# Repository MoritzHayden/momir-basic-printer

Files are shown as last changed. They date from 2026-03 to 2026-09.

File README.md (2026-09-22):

# Momir Basic Printer (MBP)

Momir Basic Printer (MBP) is a set of Python scripts designed to run headless on a Raspberry Pi connected to a thermal receipt printer for playing the [Momir Basic](https://magic.wizards.com/en/formats/momir-basic) MTG format.

If you are looking for the ESP32-based version, reference the [esp32](https://github.com/MoritzHayden/momir-basic-printer/tree/esp32) branch.

## Table of Contents

- [About](#about)
- [Momir Basic Rules](#momir-basic-rules)
- [Examples](#examples)
- [Hardware](#hardware)
  - [Components](#components)
  - [Diagram](#diagram)
  - [Photos](#photos)
- [Installation](#installation)
- [Service Management](#service-management)
- [Configuration](#configuration)
- [Disclaimer](#disclaimer)

## About

Downloads card data from the [Scryfall API](https://scryfall.com/docs/api), including card art which is dithered to monochrome on-device, and prints a random card within a set CMC value on demand via thermal printer. All settings are configurable via [config.ini](src/config.ini), and the software can run as a background service on any Linux-based SBC with GPIO. The complete hardware setup is designed to be compact and portable, with all components housed in a waterproof case.

## Momir Basic Rules

- Number of Players: 2
- Starting Life Total: 24
- Game Duration: 10 minutes
- Deck Size: 60+ basic lands

Each turn players discard a basic land to activate Momir Vig's ability and get a random creature from throughout Magic's history!

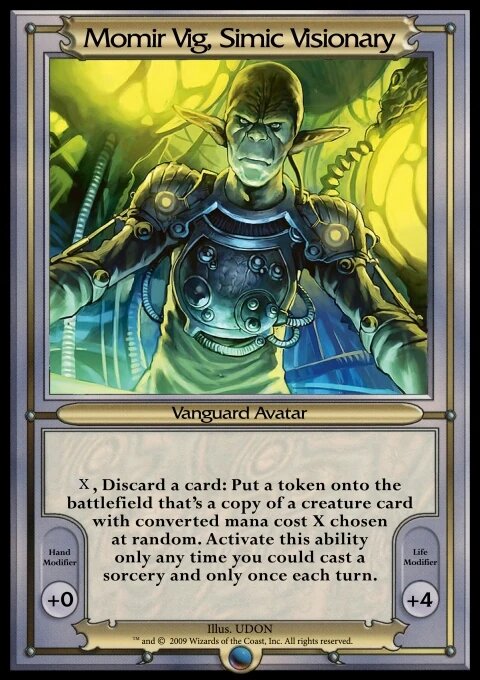
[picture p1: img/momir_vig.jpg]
Momir Vig, Simic Visionary


## Examples

| Physical Card | Printed Card |
| --- | --- |
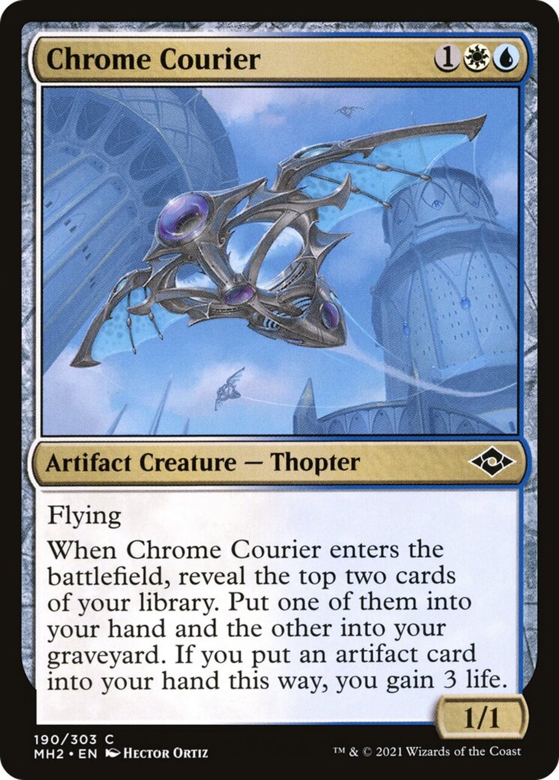
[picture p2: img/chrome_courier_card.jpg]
Physical Chrome Courier
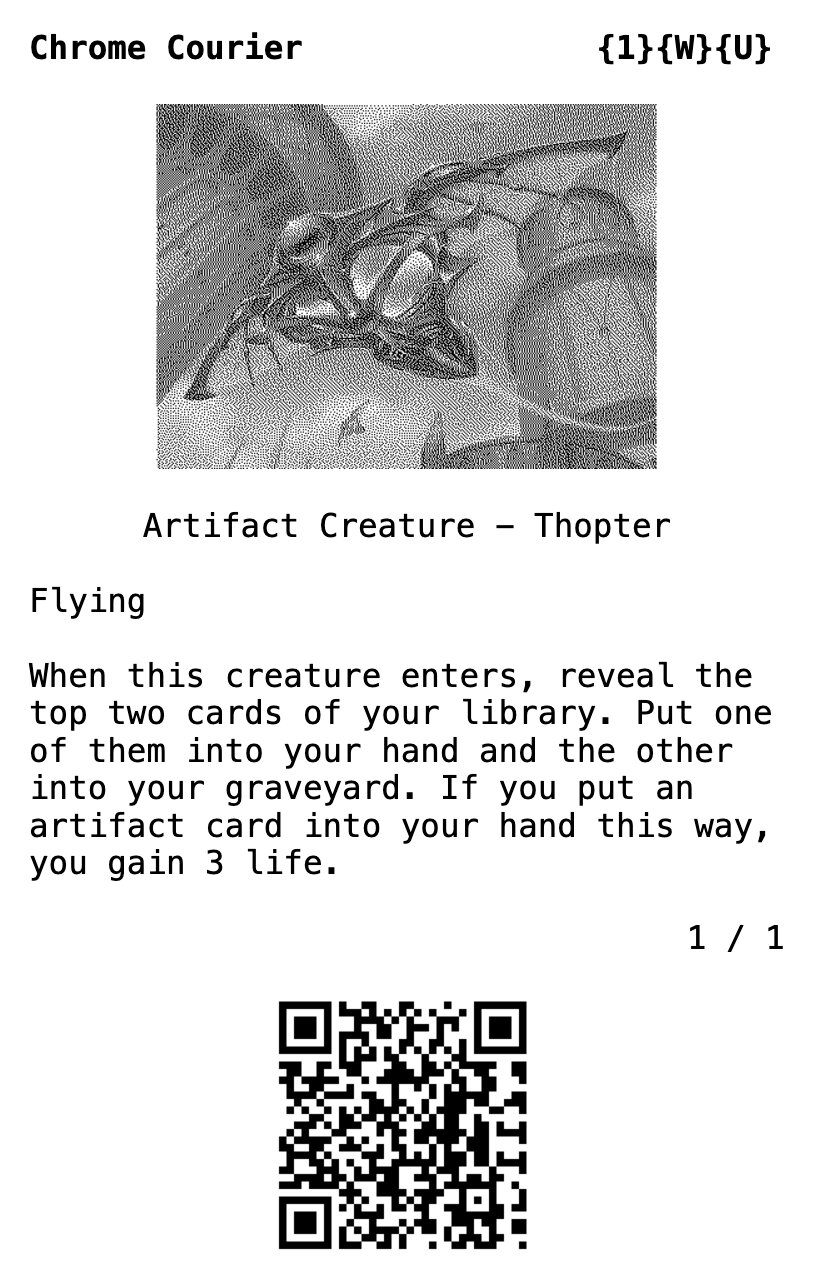
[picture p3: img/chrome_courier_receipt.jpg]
Printed Chrome Courier
|  |  |

## Hardware

### Components

- [Raspberry Pi 3 Model B+](https://www.raspberrypi.com/products/raspberry-pi-3-model-b-plus/)
- [Adafruit T-Cobbler Plus GPIO Breakout](https://a.co/d/0fnKGt3A)
- [REXQualis Electronics Component Kit](https://a.co/d/0cdCxCCP)
- [Maikrt MC206H Thermal Printer](https://a.co/d/06qIKsng)
- [PAPRMA 57mm x 30mm Thermal Paper](https://a.co/d/04u2Gb2j)
- [MakerFocus 20200330-SD8V OLED Display](https://a.co/d/06Y7V5Uj)
- [KY-040 Rotary Encoder Module](https://a.co/d/0hN4SBto)
- [Nilight 12V 20A SPST Rocker Toggle Switch](https://a.co/d/02VcvtcQ)
- [SHNITPWR 60W Universal Power Supply](https://a.co/d/0bKNzwey)
- [LM2596 Buck Converter](https://a.co/d/070NjEDp)
- [KeeYees 4 Channel IIC I2C Logic Level Converter](https://a.co/d/0ecOK7n6)
- [Enclosure Body](stl/enclosure_body.stl) ([source](https://www.printables.com/model/1735878-momir-basic-all-in-one-mtg-printer))
- [Enclosure Lid](stl/enclosure_lid.stl) ([source](https://www.printables.com/model/1735878-momir-basic-all-in-one-mtg-printer))

### Diagram

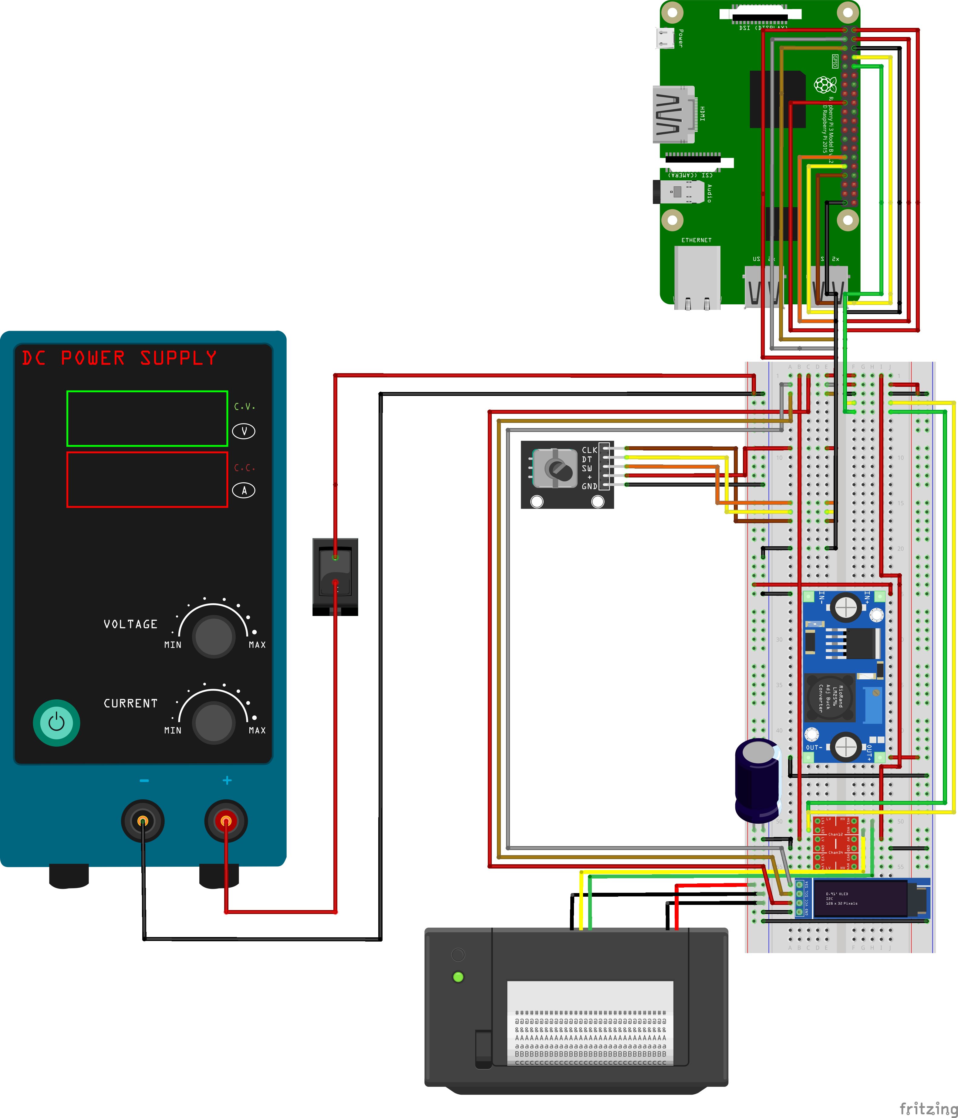
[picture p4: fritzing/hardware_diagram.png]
Hardware Diagram


### Photos

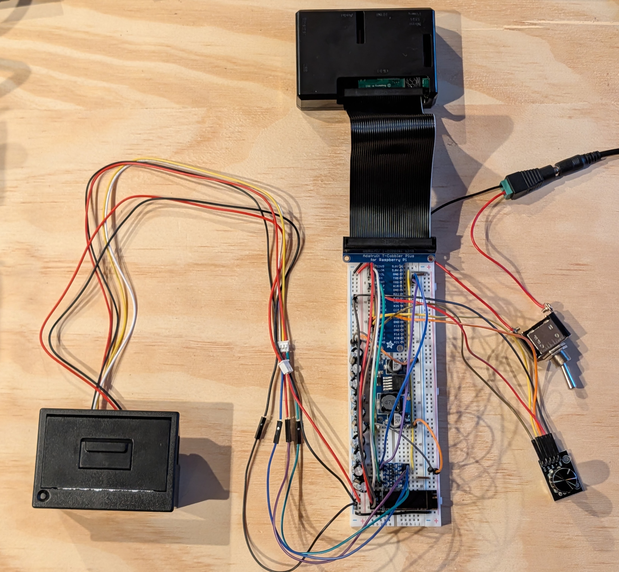
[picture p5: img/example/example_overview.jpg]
Example Overview


Example IO

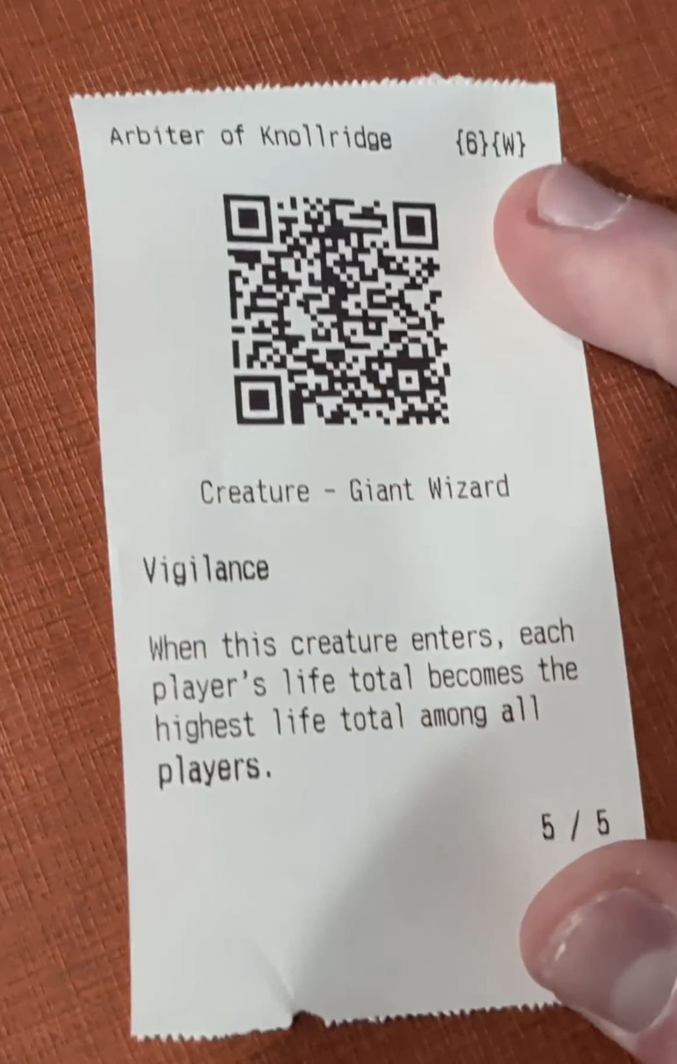
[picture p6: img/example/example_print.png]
Example Print


## Installation

1. Clone this repository and navigate to the project directory.

```shell
git clone https://github.com/MoritzHayden/momir-basic-printer.git
cd momir-basic-printer
```

2. Open [src/config.ini](src/config.ini) in a text editor and update the configuration variables to add your specific settings (like printer connection details, GPIO pins, and other hardware settings) before proceeding.

```shell
nano src/config.ini
```

3. Make the setup script executable and run it. This will automatically install dependencies and configure the systemd background service.

```shell
chmod +x setup.sh
./setup.sh
```

> [!TIP]
> If you are running a minimal setup and explicitly require the service to run as root, you can bypass the safety check by running: `sudo ./setup.sh --allow-root`

## Service Management

View live logs and print statements:

```shell
sudo journalctl -u momir-basic-printer.service -f
```

Check the current status of the service:

```shell
sudo systemctl status momir-basic-printer.service
```

Restart the service (required after making code changes):

```shell
sudo systemctl restart momir-basic-printer.service
```

Stop the service:

```shell
sudo systemctl stop momir-basic-printer.service
```

## Configuration

All configuration variables are stored in [src/config.ini](src/config.ini). Update the values in this file to match your specific hardware setup and preferences. After making changes to the configuration, restart the service for the changes to take effect.

| **Section**  | **Variable** | **Type**  | **Description** |
| --- | --- | --- | --- |
| `APP` | `booting_status` | `string`  | Status string shown while services initialize |
| `APP` | `ready_status` | `string`  | Status string shown when the appliance is idle/ready |
| `APP` | `refreshing_status` | `string`  | Status string shown during initial data refresh |
| `APP` | `fetching_status` | `string`  | Status string shown while selecting/fetching a card |
| `APP` | `printing_status` | `string`  | Status string shown while sending output to printer |
| `APP` | `cancelled_status` | `string`  | Status string shown when active work is cancelled |
| `APP` | `error_status` | `string`  | Status string shown when fetch/print fails |
| `APP` | `reset_status` | `string`  | Status string shown after long-press reset |
| `APP` | `done_status` | `string`  | Status string shown briefly after a successful print completes |
| `APP` | `done_status_seconds` | `float` | Duration in seconds to show `done_status` before returning to ready state |
| `APP` | `services_unavailable_status` | `string`  | Status string shown when printer/Scryfall services are unavailable |
| `APP` | `no_cmc_status_template` | `string`  | Template used when no card exists for selected CMC (supports `{cmc}`) |
| `APP` | `shutdown_join_timeout_seconds` | `float` | Max wait time for worker thread during shutdown |
| `FILESYSTEM` | `cards_path` | `string`  | Directory path where card JSON files are stored |
| `FILESYSTEM` | `art_path` | `string`  | Directory path where card artwork images are stored |
| `FILESYSTEM` | `default_card_art_path` | `string`  | File path to default placeholder image for cards without artwork |
| `FILESYSTEM` | `access_rights` | `octal` | File system permissions for created directories (octal notation) |
| `HARDWARE` | `serial_port` | `string`  | Serial device path for the thermal printer (e.g., `/dev/serial0`) |
| `HARDWARE` | `serial_baud_rate` | `integer` | Baud rate for the serial printer connection (e.g., `9600` or `19200`) |
| `HARDWARE` | `printer_dtr_enabled` | `boolean` | Enables GPIO-based DTR flow control; disable if the printer does not wire DTR reliably |
| `HARDWARE` | `gpio_encoder_clk` | `integer` | BCM GPIO pin for rotary encoder CLK signal (default: `13`) |
| `HARDWARE` | `gpio_encoder_dt` | `integer` | BCM GPIO pin for rotary encoder DT signal (default: `6`) |
| `HARDWARE` | `gpio_encoder_sw` | `integer` | BCM GPIO pin for rotary encoder push-button switch (default: `5`) |
| `HARDWARE` | `gpio_printer_dtr` | `integer` | BCM GPIO pin for printer DTR hardware flow control (default: `17`) |
| `HARDWARE` | `printer_dtr_active_high` | `boolean` | Whether the printer asserts DTR HIGH when its receive buffer is full |
| `HARDWARE` | `i2c_address` | `hex` | I2C hex address of the SSD1306 OLED display (default: `0x3C`) |
| `HARDWARE` | `i2c_port` | `integer` | I2C bus port number (default: `1`) |
| `HARDWARE` | `oled_width` | `integer` | OLED display width in pixels (default: `128`) |
| `HARDWARE` | `oled_height` | `integer` | OLED display height in pixels (default: `64`) |
| `HARDWARE` | `display_font_size_cmc` | `integer` | Font size for the main CMC text on OLED |
| `HARDWARE` | `display_font_size_status` | `integer` | Font size for the status text on OLED |
| `HARDWARE` | `display_status_y_offset` | `integer` | Vertical Y offset (px) for status text region |
| `HARDWARE` | `display_status_default` | `string`  | Default status text shown during display initialization |
| `HARDWARE` | `display_font_cmc_path` | `string`  | Font file path used for CMC text rendering |
| `HARDWARE` | `display_font_status_path` | `string`  | Font file path used for status text rendering |
| `HARDWARE` | `display_cmc_prefix` | `string`  | Prefix label used before current CMC value (e.g., `CMC:`) |
| `HARDWARE` | `display_padding_x` | `integer` | Left/right OLED padding in pixels for CMC and status text layout |
| `HARDWARE` | `display_cmc_value_gap` | `integer` | Horizontal pixel gap between the CMC prefix label and numeric CMC value |
| `HARDWARE` | `hold_time` | `float` | Seconds the encoder button must be held for a long-press action |
| `HARDWARE` | `cmc_min` | `integer` | Minimum selectable CMC value (default: `0`) |
| `HARDWARE` | `cmc_max` | `integer` | Maximum selectable CMC value (default: `16`) |
| `HARDWARE` | `dtr_poll_interval` | `float` | Seconds between DTR pin polls when printer buffer is full |
| `HARDWARE` | `printer_dtr_timeout_seconds` | `float` | Max time to wait on DTR before bypassing hardware flow control until restart |
| `LOGGING` | `log_level` | `string`  | Logging verbosity level (`DEBUG`, `INFO`, `WARNING`, `ERROR`, `CRITICAL`) |
| `LOGGING` | `log_format` | `string`  | Format string for log messages |
| `LOGGING` | `log_date_format` | `string`  | Format string for timestamps in log messages |
| `PRINTER` | `paper_width_mm` | `integer` | Physical width of thermal paper in millimeters |
| `PRINTER` | `paper_width_chars` | `integer` | Maximum number of characters per line for text wrapping |
| `PRINTER` | `card_art_enabled` | `boolean` | Whether to print card artwork images on receipts |
| `PRINTER` | `qr_code_enabled` | `boolean` | Whether to print QR codes linking to Scryfall card details |
| `PRINTER` | `qr_code_size` | `integer` | Size of QR code in printer units (larger = bigger QR code) |
| `PRINTER` | `dpi` | `integer` | Printer resolution in dots per inch for image rendering |
| `PRINTER` | `vendor_id` | `hex` | USB vendor ID for the thermal printer device |
| `PRINTER` | `product_id` | `hex` | USB product ID for the thermal printer device |
| `PRINTER` | `printer_profile` | `string`  | ESC/POS printer profile name for compatibility |
| `PRINTER` | `printer_media_width_px` | `integer` | Media width in pixels for image processing and scaling |
| `PRINTER` | `min_title_spacing` | `integer` | Minimum spaces between card name and mana cost on title line |
| `PRINTER` | `paragraph_spacing` | `string`  | Escaped spacing appended after wrapped oracle text paragraphs |
| `PRINTER` | `text_replacements_json` | `json` | Character replacement map for printer-safe text normalization |
| `SCRYFALL` | `base_url` | `string`  | Base URL for Scryfall API requests |
| `SCRYFALL` | `bulk_data_endpoint` | `string`  | API endpoint path for bulk card data download |
| `SCRYFALL` | `header_accept` | `string`  | HTTP Accept header value for API content negotiation |
| `SCRYFALL` | `header_user_agent` | `string`  | HTTP User-Agent header identifying the client application |
| `SCRYFALL` | `header_accept_encoding` | `string`  | HTTP Accept-Encoding header for compression support |
| `SCRYFALL` | `request_delay_seconds` | `float` | Delay between consecutive API requests to respect rate limits |
| `SCRYFALL` | `max_retries` | `integer` | Maximum number of retry attempts for failed API requests |
| `SCRYFALL` | `art_width_px` | `integer` | Target width in pixels for downloaded card artwork |
| `SCRYFALL` | `excluded_sets` | `list` | Comma-separated card sets to exclude (e.g., `funny`, `memorabilia`) |
| `SCRYFALL` | `excluded_layouts` | `list` | Comma-separated card layouts to exclude (e.g., `token`, `emblem`) |

## Disclaimer

Neither this project nor its contributors are associated with Hasbro, Wizards of the Coast, or _Magic: The Gathering_ in any way whatsoever.

<div align="center">
  <p>Copyright &copy; 2026 Hayden Moritz</p>
</div>

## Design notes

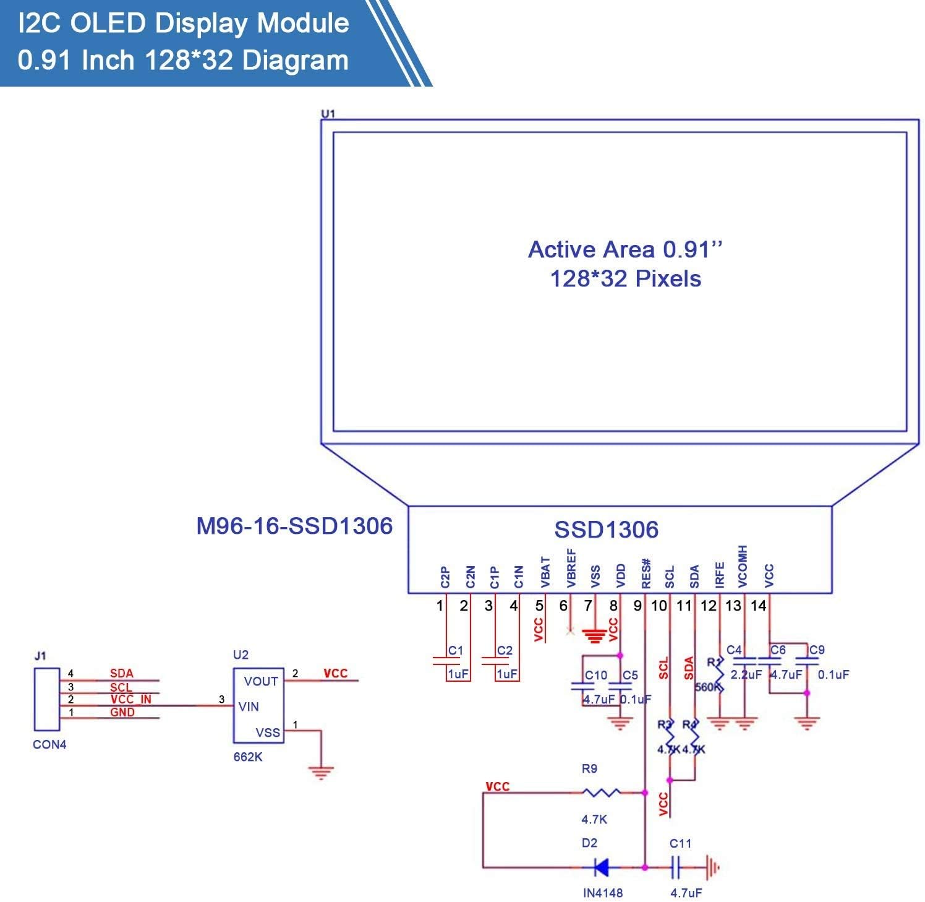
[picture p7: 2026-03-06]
img/reference/oled_display_pinout.jpg

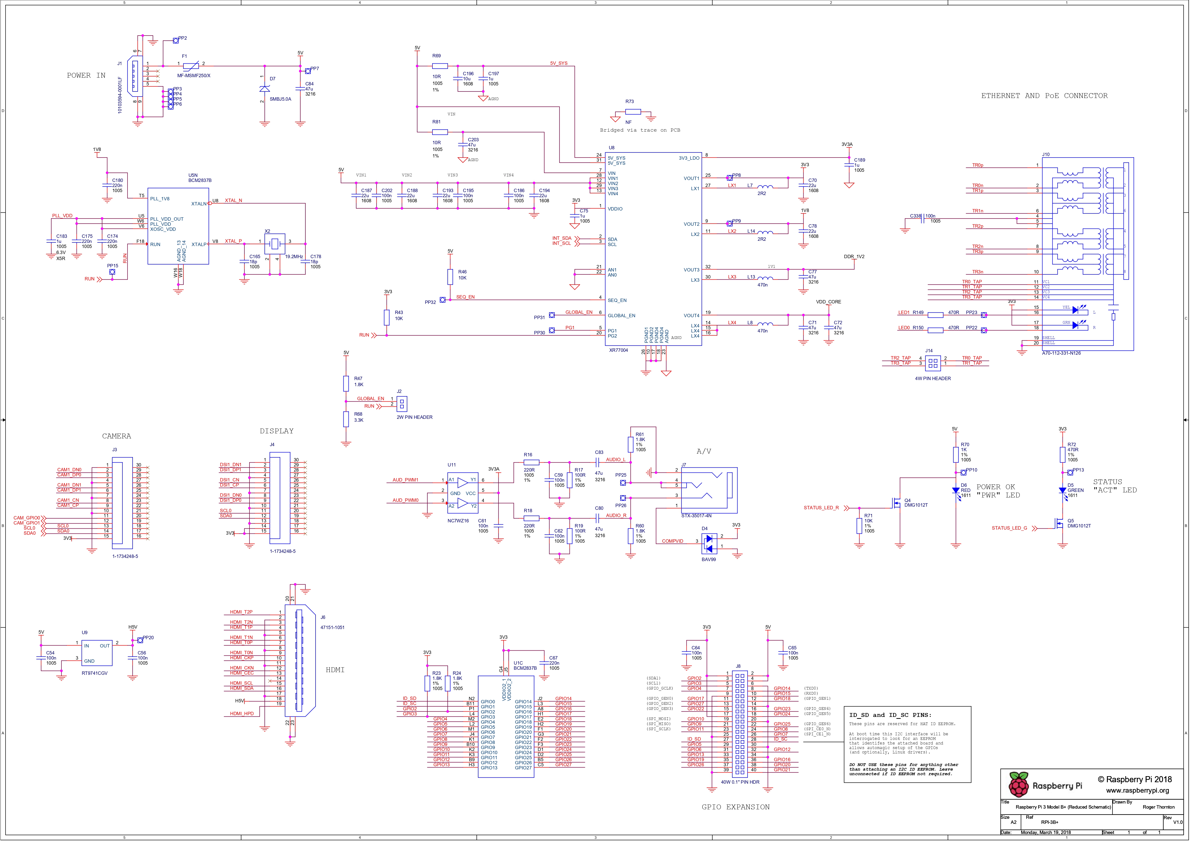
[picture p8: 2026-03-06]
img/reference/raspberry_pi_schematic.jpg

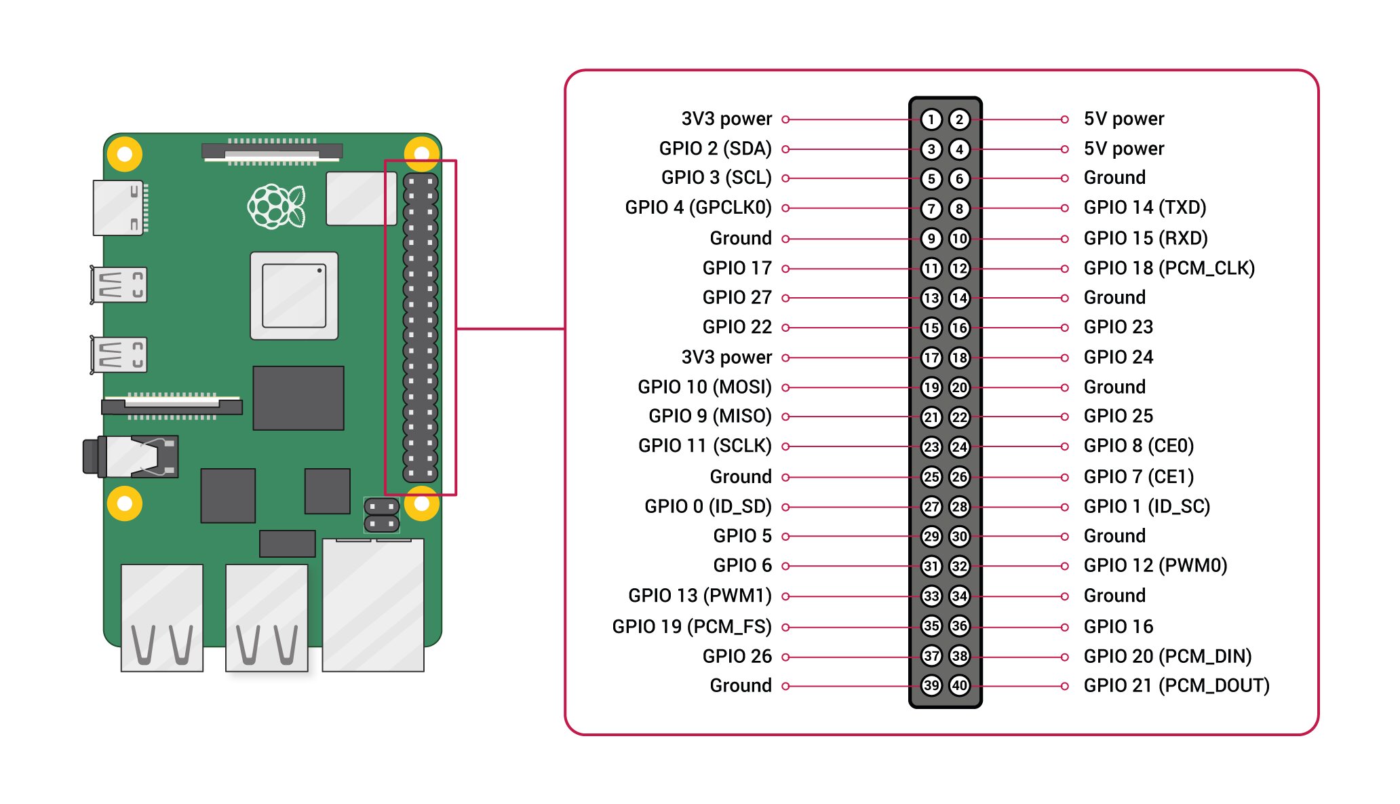
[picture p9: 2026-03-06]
img/reference/raspberry_pi_gpio_pinout_1.jpg

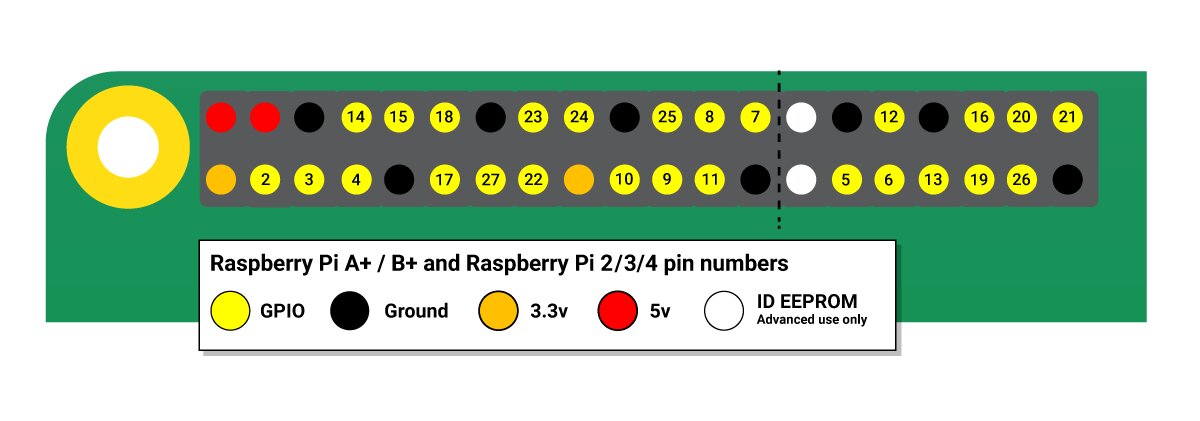
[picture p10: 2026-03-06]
img/reference/raspberry_pi_gpio_pinout_2.jpg

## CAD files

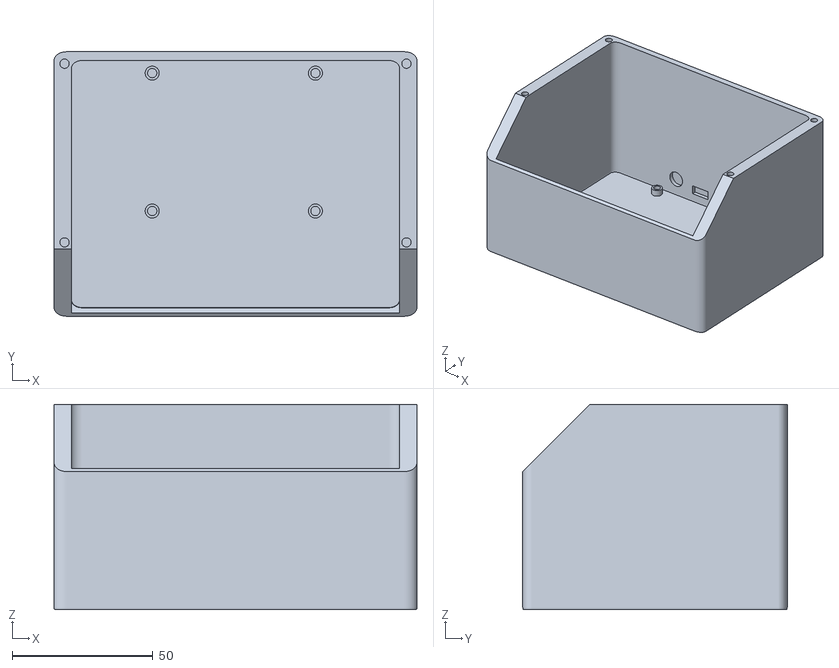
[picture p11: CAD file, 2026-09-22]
stl/enclosure_body.stl
129.0 x 94.0 x 73.0

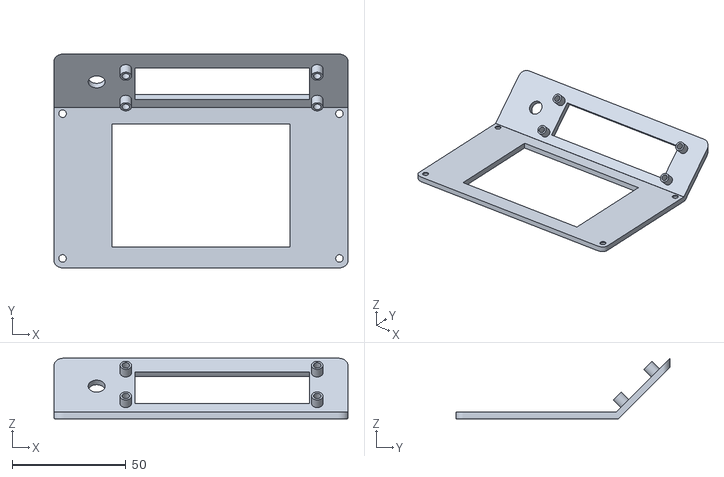
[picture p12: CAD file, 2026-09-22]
stl/enclosure_lid.stl
129.0 x 94.0 x 26.7

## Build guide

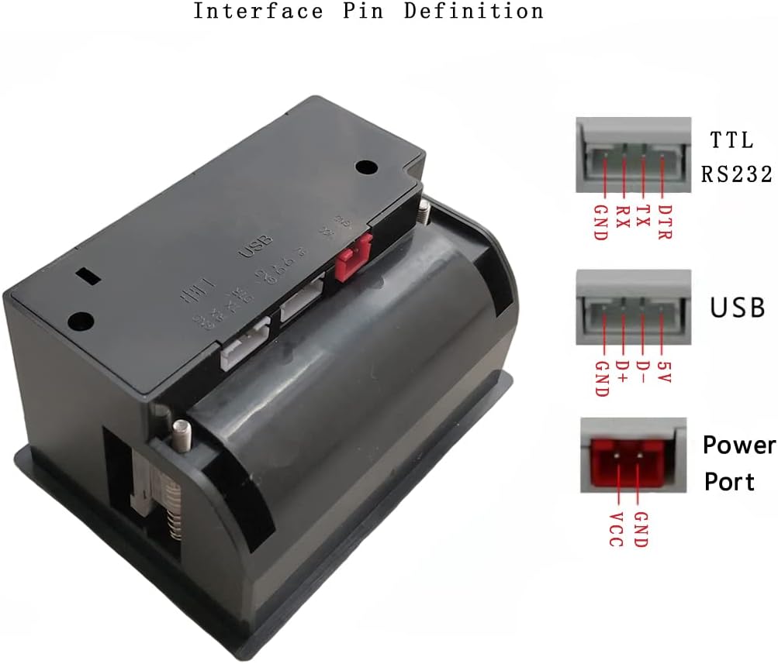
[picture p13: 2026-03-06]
img/reference/thermal_printer_pinout.jpg

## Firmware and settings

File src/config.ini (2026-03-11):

[APP]
booting_status = Booting...
ready_status = Ready
refreshing_status = Refreshing...
fetching_status = Fetching...
printing_status = Printing...
cancelled_status = Cancelled
error_status = Error
reset_status = Reset
services_unavailable_status = Services N/A
no_cmc_status_template = No CMC {cmc}
shutdown_join_timeout_seconds = 5
printed_status_name_max_len = 20

[FILESYSTEM]
cards_path = ./cards
art_path = ./cards/art
default_card_art_path = ./img/default_card_art.jpg
access_rights = 0o777

[HARDWARE]
serial_port = /dev/serial0
serial_baud_rate = 9600
printer_dtr_enabled = True
gpio_encoder_clk = 13
gpio_encoder_dt = 6
gpio_encoder_sw = 5
gpio_printer_dtr = 17
printer_dtr_active_high = True
i2c_address = 0x3C
i2c_port = 1
oled_width = 128
oled_height = 64
display_font_size_cmc = 36
display_font_size_status = 12
display_status_y_offset = 52
display_status_default = Ready
display_font_cmc_path = /usr/share/fonts/truetype/dejavu/DejaVuSans-Bold.ttf
display_font_status_path = /usr/share/fonts/truetype/dejavu/DejaVuSans.ttf
display_cmc_prefix = CMC:
hold_time = 1.5
cmc_min = 0
cmc_max = 16
dtr_poll_interval = 0.05
printer_dtr_timeout_seconds = 3.0

[LOGGING]
log_level = DEBUG
log_format = [%%(levelname)s] [%%(asctime)s] %%(name)s: %%(message)s
log_date_format = %%Y-%%m-%%d %%H:%%M:%%S

[PRINTER]
paper_width_mm = 57
paper_width_chars = 38
card_art_enabled = True
qr_code_enabled = True
qr_code_size = 6
dpi = 203
vendor_id = 0x1234
product_id = 0x5678
printer_profile = simple
printer_media_width_px = 380
min_title_spacing = 1
paragraph_spacing = \n\n
text_replacements_json = {"\u2014":"-","\u2013":"-","\u2019":"'","\u201c":"\"","\u201d":"\""}

[SCRYFALL]
base_url = https://api.scryfall.com
bulk_data_endpoint = /bulk-data/oracle_cards
header_accept = application/json
header_user_agent = MoritzHayden/momir-basic-printer
header_accept_encoding = gzip
request_delay_seconds = 0.05
max_retries = 3
art_width_px = 380
excluded_sets = funny,
                memorabilia,
                minigame,
                alchemy
excluded_layouts = token,
                   emblem,
                   art_series,
                   double_faced_token,
                   scheme,
                   planar,
                   phenomenon,
                   vanguard,
                   augment,
                   host

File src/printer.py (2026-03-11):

"""Thermal printer interface for printing Magic: The Gathering cards."""

import logging
import json
import threading
import textwrap
import time
from pathlib import Path
from typing import Any, Dict, Optional

import gpiozero
from escpos.printer import Serial
from PIL import Image

logger = logging.getLogger('momir.printer')


class Printer:
    """Thermal printer interface for printing Magic: The Gathering cards.

    This class handles:
    - Formatting card data for thermal printer output
    - Printing card images, text, and QR codes
    - Text cleaning and wrapping for proper display
    - DTR-based hardware flow control on the serial thermal printer
    """

    def __init__(self, printer_config, filesystem_config, hardware_config=None) -> None:
        """Initialize printer with configuration.

        Args:
            printer_config: Configuration section for printer settings
            filesystem_config: Configuration section for filesystem paths
            hardware_config: Optional configuration section for GPIO/serial settings
        """
        # Printer configuration
        self.paper_width_mm: int = printer_config.getint('paper_width_mm')
        self.paper_width_chars: int = printer_config.getint(
            'paper_width_chars')
        self.card_art_enabled: bool = printer_config.getboolean(
            'card_art_enabled')
        self.qr_code_enabled: bool = printer_config.getboolean(
            'qr_code_enabled')
        self.qr_code_size: int = printer_config.getint('qr_code_size')
        self.dpi: int = printer_config.getint('dpi')
        self.vendor_id: int = int(printer_config.get('vendor_id'), 0)
        self.product_id: int = int(printer_config.get('product_id'), 0)

        # Serial configuration (from [HARDWARE] or fallbacks)
        if hardware_config is not None:
            self.serial_port: str = hardware_config.get(
                'serial_port', fallback='/dev/serial0')
            self.serial_baud_rate: int = hardware_config.getint(
                'serial_baud_rate', fallback=9600)
            self._dtr_enabled: bool = hardware_config.getboolean(
                'printer_dtr_enabled', fallback=True)
            self._dtr_pin: int = hardware_config.getint(
                'gpio_printer_dtr', fallback=17)
            self._dtr_active_high: bool = hardware_config.getboolean(
                'printer_dtr_active_high', fallback=True)
            self._dtr_poll_interval: float = hardware_config.getfloat(
                'dtr_poll_interval', fallback=0.05)
            self._dtr_timeout_seconds: float = hardware_config.getfloat(
                'printer_dtr_timeout_seconds', fallback=3.0)
        else:
            self.serial_port = '/dev/serial0'
            self.serial_baud_rate = 9600
            self._dtr_enabled = True
            self._dtr_pin = 17
            self._dtr_active_high = True
            self._dtr_poll_interval = 0.05
            self._dtr_timeout_seconds = 3.0

        self._dtr_disabled_runtime = not self._dtr_enabled

        self.printer_profile: str = printer_config.get(
            'printer_profile', fallback='simple')
        self.printer_media_width_px: Optional[int] = printer_config.getint(
            'printer_media_width_px', fallback=None)
        self._min_title_spacing: int = printer_config.getint('min_title_spacing', fallback=1)
        self._paragraph_spacing: str = printer_config.get(
            'paragraph_spacing', fallback='\\n\\n').encode('utf-8').decode('unicode_escape')
        text_replacements_json = printer_config.get(
            'text_replacements_json',
            fallback='{"\\u2014":"-","\\u2013":"-","\\u2019":"\'","\\u201c":"\\\"","\\u201d":"\\\""}',
        )
        try:
            self._text_replacements: Dict[str, str] = json.loads(text_replacements_json)
        except json.JSONDecodeError as exc:
            raise ValueError(f"Invalid text_replacements_json in config: {exc}") from exc

        # DTR monitoring is optional because some printers leave the line floating.
        self._dtr_device = None
        if self._dtr_enabled:
            self._dtr_device = gpiozero.InputDevice(self._dtr_pin, pull_up=False)

        # Filesystem paths (use __file__ for reliability)
        base_path = Path(__file__).resolve().parent.parent
        self.cards_path: Path = base_path / filesystem_config.get('cards_path')
        self.art_path: Path = base_path / filesystem_config.get('art_path')
        self.default_card_art_path: Path = base_path / \
            filesystem_config.get('default_card_art_path')
        self.access_rights: int = int(
            filesystem_config.get('access_rights'), 0)

        # Ensure runtime directories exist so app can boot on a fresh install.
        self.cards_path.mkdir(parents=True, exist_ok=True, mode=self.access_rights)
        self.art_path.mkdir(parents=True, exist_ok=True, mode=self.access_rights)

        # Validate configuration
        self._validate_config()

    def _validate_config(self) -> None:
        """Validate critical configuration values on initialization.

        Raises:
            ValueError: If critical configuration is missing or invalid
        """
        if self.paper_width_chars <= 0:
            raise ValueError(
                f"paper_width_chars must be positive, got {self.paper_width_chars}")

        if self.qr_code_size <= 0:
            raise ValueError(
                f"qr_code_size must be positive, got {self.qr_code_size}")

        if self.printer_media_width_px is not None and self.printer_media_width_px <= 0:
            raise ValueError(
                "printer_media_width_px must be positive when provided")

    def __repr__(self) -> str:
        """String representation for debugging."""
        return (f"Printer(serial='{self.serial_port}', "
                f"baud={self.serial_baud_rate}, "
            f"profile='{self.printer_profile}', "
            f"paper_width_chars={self.paper_width_chars})")

    def clean_text(self, text: str) -> str:
        """Clean text for thermal printer compatibility.

        Replaces special Unicode characters with ASCII equivalents
        that the thermal printer can handle.

        Args:
            text: Input text to clean

        Returns:
            Cleaned text with replaced characters
        """
        cleaned = text
        for old_char, new_char in self._text_replacements.items():
            cleaned = cleaned.replace(old_char, new_char)
        # Encode to CP437 (standard ASCII/IBM code page) so that python-escpos's
        # MagicEncode never needs to switch to a non-Latin codepage (e.g. GBK).
        # Characters outside CP437 are replaced with '?' rather than triggering
        # a codepage switch that would corrupt the entire subsequent print stream.
        cleaned = cleaned.encode('cp437', errors='replace').decode('cp437')
        return cleaned

    def _is_dtr_busy(self) -> bool:
        if self._dtr_device is None:
            return False
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

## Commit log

2026-03-05 feat: add printer virtualization
2026-03-11 fix: update printer dtr
    [config.ini, main.py, printer.py]
2026-03-11 feat: update print order
2026-03-11 fix: update rotary encoder
    [main.py]
2026-03-11 fix: rotary encoder wrapping
    [main.py]
2026-03-11 fix: thread race condition
    [main.py, printer.py]
2026-03-11 fix: printer charcodes
2026-03-14 docs: add hardware diagram
    [hardware_diagram.fzz]
2026-09-22 docs: update documentation
    [enclosure_body.stl, enclosure_lid.stl]
